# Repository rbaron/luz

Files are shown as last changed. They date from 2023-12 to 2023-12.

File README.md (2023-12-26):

# luz
An experiment in USB-C power delivery.

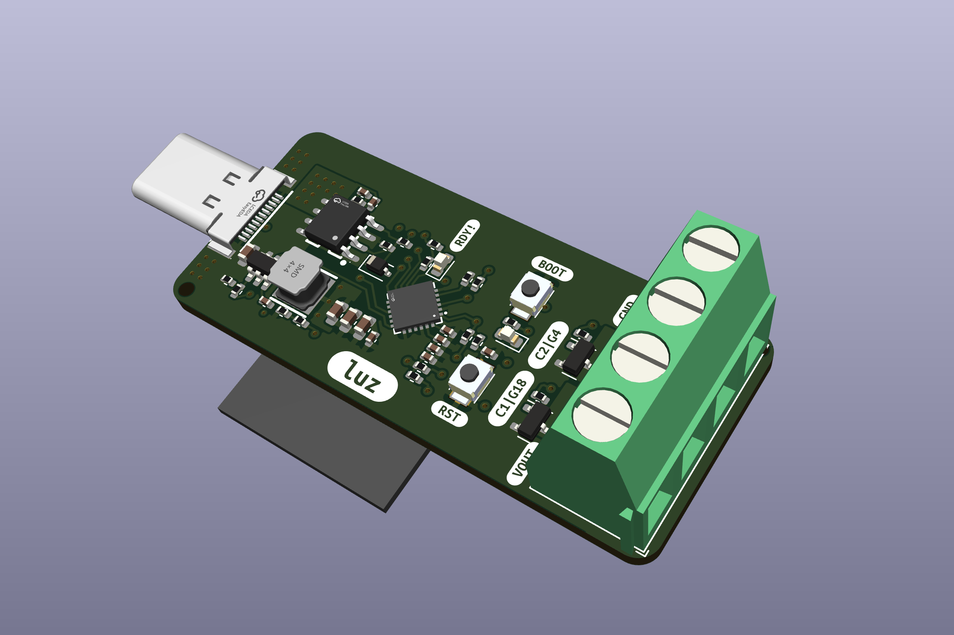
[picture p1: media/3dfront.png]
PCB render front


This repo contains printed circuit board fabrication files and firmware sample for a basic USB-C power delivery "trigger board" with an accompanying ESP32.

## Hardware
The CYPD3177 IC is used to negotiate power contracts with USB-C power supplies, and communicates with the onboard ESP32 via I2C for control and monitoring.

Once the required power delivery contract is successfully negotiated, the ESP32 may control two MOSFET channels to switch power to two different loads. The original use case is to deliver 12 V @ 3 A to LED strips, but any load up to 3A and 20V may be used in principle.

### Main Components
- [CYPD3177](https://www.infineon.com/cms/en/product/universal-serial-bus/usb-c-charging-port-controllers/ez-pd-barrel-connector-replacement-bcr/cypd3177-24lqxq/) USB-C PD controller
- ESP32-WROOM-32
  - For this prototype I used this older module since I still have a bunch of them around.

## Software
The CYPD3177 is configured during runtime via I2C. I implemented the `cypd3177` component in an [ESPHome](https://esphome.io/) fork (at [rbaron/esphome/cypd3177](https://github.com/rbaron/esphome/tree/cypd3177)).

In this repo there are sample `yaml` files under [./code/esphome](./code/esphome) that uses the `cypd3177` as an external component.

To configure a power delivery contract, set up the `cypd3177` component in ESPHome as for example:
```yaml
cypd3177:
  interrupt_pin: GPIO23
  voltage: 9000 mV
  current: 1000 mA
```

## USB-C Power Delivery Support & Maximum Power
The CYPD3177 supports USB-C PD 3.0, but unfortunately does not support Programmable Power Supply (PPS) contracts. The board is a prototype, mostly for learning, designed to handle a maximum of only 3 A.

USB-C PD 3.0 mandates support for a few standard fixed power profiles, namely providing 5 V, 9 V, 15 V and 20 V. Some USB-C PD sources may also support 12 V. Enabling logging for the `cypd3177` component in ESPHome will show the power profiles supported by the source. For example:

```
16:08:41.416 -> [I][cypd3177.pdo:059]: Fixed PDO: 5000 mV, 3000 mA
16:08:41.416 -> [I][cypd3177.pdo:059]: Fixed PDO: 9000 mV, 3000 mA
16:08:41.416 -> [I][cypd3177.pdo:059]: Fixed PDO: 12000 mV, 2000 mA
16:08:41.416 -> [I][cypd3177.pdo:059]: Fixed PDO: 15000 mV, 2000 mA
16:08:41.416 -> [I][cypd3177.pdo:059]: Fixed PDO: 20000 mV, 1500 mA
16:08:41.416 -> [I][cypd3177.pdo:066]: Augmented SPR_PPS PDO: 3300 - 11000 mV, 3000 mA
```

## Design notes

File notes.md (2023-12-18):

# ICs
- [STUSB4500](https://www.st.com/en/interfaces-and-transceivers/stusb4500.html)
  - $2 on JLCPCB
  - Open source project that uses it
    - [schematic](https://github.com/oxplot/fpx/blob/master/board/schematics.svg)
  - [Eval board](https://www.st.com/resource/en/data_brief/eval-scs001v1.pdf)
  - Main transistor on VBus_EN_SNK
    - How important is the power dissipation? Well very, ofc
    - Recommended on datasheet [STL6P3LLH6](https://www.st.com/resource/en/datasheet/stl6p3llh6.pdf)
      - -30V, -6A, 30mOhm, 3W
      - Max Vgs +-12
    - [AO3401A](https://datasheet.lcsc.com/lcsc/1810171817_Alpha---Omega-Semicon-AO3401A_C15127.pdf)
      - -30V, -4A, Rdson 100mOhm, 1W
      - Vth -1V
      - At
    - []()
    - [IRFR9024NTRPBF](https://www.mouser.ch/datasheet/2/196/Infineon_IRFR9024N_DataSheet_v01_01_EN-3363169.pdf)
      - -55V, -11A, Rdson 0.2O0hm, 38W
      - Vth max -4V
      - Max Vgs -20V, more confortable limit
      - But Rdson is high
        - At 5A, 0.2 Ohm = 5W, that's a lot of wasted power
    - [SSM3J332R](https://datasheet.lcsc.com/lcsc/1806140422_TOSHIBA-SSM3J332R-LF_C146367.pdf)
      - -30V, -6A, Rdson 0.050Ohm, 1W
      - Vth ~ -1V
      - Rdson @ -12V 0.05. At 5A = 0.25W, sounds good.
      - Max Vgs -12V, so we're close to the limit
    - [IRF9Z34NSTRLPBF](https://jlcpcb.com/partdetail/181165-IRF9Z34NSTRLPBF/C169780)
      - +- 20V Vgs, but 0.1 mOhm. At 5Amps, 2.5W, it's a lot
    - [DMP3028LFDE](https://jlcpcb.com/partdetail/DiodesIncorporated-DMP3028LFDE13/C150441)
      - [datasheet](https://www.diodes.com/assets/Datasheets/DMP3028LFDE.pdf)
      - Vgs +-20V, 5 Amps
      - 0.4 W only power dissipation
      - Rdson 0.04 Ohm. At 5 Amps, it's 1.25 W, above the 0.4 W limit
    - [AOD413A](https://jlcpcb.com/parts/componentSearch?searchTxt=AOD413A)
      - -40V, -12A, Rdson 0.045 Ohm, 1.5W
			- Vgs +-20V
    - [dmp3098lsd-13](https://datasheet.lcsc.com/lcsc/2009161504_Diodes-Incorporated-DMP3098LSD-13_C531177.pdf)
      - Dual P Channel
      - Used by Phil's design
      - Abs max Vgs +-20V, only 4.4 A?
    - [DMP3056LSS](https://datasheet.lcsc.com/lcsc/1806090929_Diodes-Incorporated-DMP3056LSS-13_C110502.pdf)
      - -30V, -6A, 0.045 Ohm, 1.5W
    - [SI4909DY-T1-GE3](https://www.digikey.ch/en/products/detail/vishay-siliconix/SI4909DY-T1-GE3/4439625)
      - 40V 8A 27mΩ@10V,8A 3.2W
      - [datasheet](https://datasheet.lcsc.com/lcsc/1806030436_Vishay-Intertech-SI4909DY-T1-GE3_C222523.pdf)
      -

# PD
	- Note that 12V is not part of the spec, but it's a common voltage. Anker apparently does not implement it?
  	- What if we request 15V @ 5A and add a buck converter to 12V?
	- Max 100 W (let's design for 100W but aim for max 50W for safety)
  	- At 12V, that's 8.3A
  	- But actually max current is 5A, only reaches 100W @ 20V
  	- So we can design with a 5A limit for the MOSFETs while observing the 100W limit
	- LED strips
  	- Depends on density of leds, ceiling is around 20 W/m, so we could power ~5 m tops at 100W. But at 12V, we're looking more at around 60-ish W. Realistic, lets aim for 3 m.
  	- At 12 V, that would be 20 * 3 / 12 = 2.5 A across however many channels we have

# ESP32-S3
- [Phil's design](https://www.youtube.com/watch?v=yxU_Kw2de08)
  - [Schematic](https://github.com/pms67/ESP32-USB-Dongle/blob/main/ESP32_USB_Dongle-Schematic.pdf)
- Regulator
  - [AP2114](https://www.diodes.com/assets/Datasheets/AP2114.pdf)
  - [HT7333](https://www.angeladvance.com/HT73xx.pdf)
    - Up to 12V
    - Max 250mA
  - [AMS1117](http://www.advanced-monolithic.com/pdf/ds1117.pdf)
    - Max 15V
    - Basic part at $0.13 on LCSC
    - Max 1A
  - [SPX3819](https://jlcpcb.com/partdetail/Maxlinear-SPX3819M5_L_3_3TR/C9055)
    - Phils uses this one
    - Max 16V (it would be nice to support 20V just in case)
    - Abolsute max +/-20V, which is ok
  - [SPX1117M3](https://jlcpcb.com/partdetail/Maxlinear-SPX1117M3_L_3_3TR/C6862)
		- Max 20V, 800 mA
		- Perfect
- [ESP32-S3-WROOM-1](https://www.espressif.com/sites/default/files/documentation/esp32-s3-wroom-1_wroom-1u_datasheet_en.pdf)
  - Contains module schematics
- Design reference
  - [Hardware design guidelines](https://www.espressif.com/sites/default/files/documentation/esp32-s3_hardware_design_guidelines_en.pdf)
    - RF
			- LNA_IN source 35 + 10j page 16
			- Using pi network for 50 Ohm antenna
			- [Pi Network calculator](https://www.eeweb.com/tools/pi-match/)
			- Antenna
  			- [ANT3216LL00R2400A](https://jlcpcb.com/partdetail/Yageo-ANT3216LL00R2400A/C293767) sounds popular
    			- Lots of use on GitHub
		- Flash
  		- Phil uses [W25Q16JVSSIQ](https://jlcpcb.com/partdetail/WinbondElec-W25Q16JVSSIQ/C82317)
  		- Discontinued in favor of [W25Q16JVSSIQ](https://jlcpcb.com/partdetail/WinbondElec-W25Q16JVSSIQ/C131025)
  		- See [ESP32-S3-WROOM-1](https://www.espressif.com/sites/default/files/documentation/esp32-s3-wroom-1_wroom-1u_datasheet_en.pdf) schematic for pins
  		- GPIO45
    		- [Default pull down (page 22)](https://cdn-shop.adafruit.com/product-files/5477/esp32-s3_datasheet_en.pdf) which makes VDD_SPI be 3.3 what we want

# USB-C
- [ESP dev board](https://www.youtube.com/watch?v=IML9c_MsyQU)
  - Male connector with tabs from JLCPCB
  - 3 A
- [C2982483](https://jlcpcb.com/partdetail/gswitch-GT_USB8012A/C2982483)
  - 24 pins
  - 5A
  - Tabs
  - Fixture required for soldering, not ideal
- [C2938596](https://jlcpcb.com/partdetail/XkbConnectivity-U261_241N4BS2SS/C2938596)
  - 5A
  - Tabs
  - [Datasheet]()
  - We'll only need the "easy to access" A* pins on the front row, convenient
  - Any board thickness, easier
- [C319150](https://jlcpcb.com/partdetail/XkbConnectivity-U261_241N4BS60/C319150)
  - PCB edge mount
  - No extra tabs
  - 5A
  -
  - [datasheet](https://datasheet.lcsc.com/lcsc/2002271811_XKB-Connectivity-U261-241N-4BS60_C319150.pdf)
    - PCB width? 0.9 mm?
      - Has to be 0.8
  - Projects using it:
    - https://github.com/tillitis/tillitis-key1
    - https://github.com/bschan9228/MInG/tree/f5a2087e46fd469d9a58bee00fa3ce4dc36beebd/Hardware/Prototype/ESP_SoC
      - Also has RF circuit
      - [PCB thickness 0.8 mm](https://github.com/bschan9228/MInG/blob/f5a2087e46fd469d9a58bee00fa3ce4dc36beebd/Hardware/Prototype/ESP_SoC/ESP_SoC/v1/PCB_OUTPUT/READ%20THIS%20FIRST.txt)
        - So it fits the USB-C connector?
        - But it will change the 4 layer impedance calculation

# Tactile Switch
- [](https://jlcpcb.com/partdetail/gswitch-GT_TC054A_H035L1/C778158)
  - Edge mounted

# Power Delivery
- 12

# LED Switching MOSFETs
- [AO3400A](https://datasheet.lcsc.com/lcsc/1811081213_Alpha---Omega-Semicon-AO3400A_C20917.pdf)
  - For low side switching the LEDs
  - But we can't really do low side given the common GND of the LED strips
  - Max Vgs -12V, but if we do low side switching, we're at 3.3V
- [AO3401A](https://datasheet.lcsc.com/lcsc/1810171817_Alpha---Omega-Semicon-AO3401A_C15127.pdf)
	- -30V, -4A, Rdson 100mOhm, 1W
	- Vth -1V
	- Vgs max -12, we'd be too close to the limit?
  	- Maybe use a voltage divider to bring it down to 10V?
  	- Or a transducer
	- At 4A, -12V Vgs, 0.05 Ohm = 0.8 W, so we're kinda good for power dissipation?
- A popular controller H801 uses a level shifter between the PWM signals and the P-channel MOSFET gates:
  - [https://tinkerman.cat/post/closer-look-h801-led-wifi-controller](teardown)
	- [HC245 datasheet](https://www.ti.com/lit/ds/symlink/sn74hc245.pdf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)
  	- [At JLCPCB](https://jlcpcb.com/partdetail/Toshiba-74VHC245FT_BE/C8096)
  	- 3.3, 5V compatible
  	-

# Barrel jack
- 5.5mm OD, 2.1mm ID
  - [Example](5.5mm 2.1mm)
  - Positive center

# Buck Converter ICs
- [TPS61175PWPR](https://jlcpcb.com/partdetail/TexasInstruments-TPS61175PWPR/C43276)
  - 3A
- [LM2596DSADJG](https://jlcpcb.com/partdetail/Onsemi-LM2596DSADJG/C92134)
  - 3A
  - SMT
- [AOZ1212](https://aosmd.com/res/data_sheets/AOZ1212AI.pdf)
  - Used by the popular H801 controller
  - 4.5V to 27V input
- [AOZ1284](https://aosmd.com/res/data_sheets/AOZ1284PI.pdf)
  -
- [digikey search2](https://www.digikey.ch/en/products/filter/voltage-regulators-dc-dc-switching-regulators/739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)
- [digikey search](https://www.digikey.ch/en/products/filter/voltage-regulators-dc-dc-switching-regulators/739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)
- [AP64501](https://www.diodes.com/assets/Datasheets/AP64501.pdf)
  - 5A, Vin max 40V
  - Efficiency 90%

# LDO
- [7812](https://datasheet.lcsc.com/lcsc/2304140030_STMicroelectronics-L7812CV_C105651.pdf)
  - 1.5 A
  - Heat?
- Options for up to 20V:
  - [Digikey query](https://www.digikey.ch/en/products/filter/voltage-regulators-linear-low-drop-out-ldo-regulators/699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)
  - [](https://jlcpcb.com/parts/componentSearch?searchTxt=LM1117MPX)
    - Max 24V
    - 500 mA
    - Perfect for us
  - [LM1117MPX-3.3/NOPB](https://jlcpcb.com/partdetail/TexasInstruments-LM1117MPX_3_3NOPB/C9662)
    - Max 20V
  - [NCP718BSN330T1G](https://www.digikey.ch/en/products/detail/onsemi/NCP718BSN330T1G/9169776)
    - Max 24V
    - But only 300mA
  - [SY8303](https://datasheet.lcsc.com/lcsc/1811151653_Silergy-Corp-SY8303AIC_C97054.pdf)
    - Buck converter input up to 40V
    - It's the one Phil uses

# ESD protection
- [ESDA25P35](https://www.mouser.ch/datasheet/2/389/esda25p35_1u1m-1848969.pdf)
  - Recommended by the STUSB4500 datasheet
  - Standoff voltage 22V
- [ESDA25W](https://jlcpcb.com/partdetail/TechPublic-ESDA25W/C3021136)
  - Operating voltage 24V
  - Dual

# TODO
- [X] Voltage divider & ADC to measure VBUS
- [X] Expose Vhigh on a connector (in addition to LED drivers), so we can use the board as a simple USB-C trigger board
- [X] Mounting holes
  - Got rid because of space
- [X] ESD protection
- [X] Barrel jack (backward voltage?)
- [X] Test pads
- [ ] Can we also make it control addressable LED strips?
- [X] Text in the back: max 12V, X watts/Amps per channel
- [X] I2C pullups
- [X] Expose I2C pins
- [X] More ground stitching vias close to the screw on connector

# Projects
- [PD Micro](https://www.crowdsupply.com/ryan-ma/pd-micro)
  - Uses PHY USB-C controller FUSB302, not all-in-one PD IC like STUSB4500
  - [Hackaday](https://hackaday.com/2021/01/16/usb-c-programmable-power-supply-for-any-project/)
  - [GitHub](https://github.com/ryan-ma/PD_Micro)
- [ZY12PDN](https://github.com/manuelbl/zy12pdn-oss)
  - Open source firmware for common PD trigger board ZY12PDN
    - FUSB302B IC
    - STM32F030F4 MCU
    - [Hardware analysis](https://github.com/manuelbl/zy12pdn-oss/wiki/Hardware-analysis)
  - Uses PPS fallback if fixed voltage not supported!
- [Brian Lough's PD trigger boards review](https://www.youtube.com/watch?v=iumAnPiQSj8)
  - [His post on IronOS](https://github.com/Ralim/IronOS/issues/24#issuecomment-651659470)
- [PicoPD](https://hackaday.io/project/192576-picopd-usb-c-pd-30-pps-trigger-with-rp2040)
  - PPS and PD capable
  - Uses the [AP33772](https://www.diodes.com/part/view/AP33772)
    - Capable of both PD and PPS!!
- [Phil's lab USB-C Power Delivery hardware design](https://www.youtube.com/watch?v=W13HNsoHj7A)
  - Uses [CYPD3177](https://www.infineon.com/dgdl/Infineon-EZ-PD_BCR_Datasheet_USB_Type-C_Port_Controller_for_Power_Sinks-DataSheet-v03_00-EN.pdf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)
    - Does not support PPS, but [CYPD3171](https://www.infineon.com/dgdl/Infineon-EZ-PD(TM)_CCG3PA_Datasheet_USB_Type-C_Port_Controller-DataSheet-v09_00-EN.pdf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) does
    - Has built-in overvoltage protection and short to vbus protection

# PD / PPS ICs
- [STUSB4500](https://www.st.com/en/interfaces-and-transceivers/stusb4500.html)
  - The one I used
  - [datasheet](https://www.st.com/resource/en/datasheet/stusb4500l.pdf)
  - No PPS, but [alternatives](https://community.st.com/t5/interface-and-connectivity-ics/how-do-i-configure-the-stusb4500-as-a-pps-sink/m-p/251067/highlight/true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)
- [STUSB1602](https://www.mouser.ch/datasheet/2/389/stusb1602-1852125.pdf)
  - [datasheet](file:///Users/rbaron/Downloads/stusb1602%20(1).pdf)
  - PPS support
  - Overvoltage protection and short to vbus protection
  - [P-NUCLEO-USB002](https://www.st.com/en/evaluation-tools/p-nucleo-usb002.html)
    - STM32 + STUSB1602 dev board
    - $60 on digikey
- [FUSB302](https://datasheet.lcsc.com/lcsc/1809111642_onsemi-FUSB302BMPX_C132291.pdf)
  - Popular, lower level
  - [OSS library](https://github.com/Ralim/usb-pd)
  - How does it work?
    - [BMC](https://en.wikipedia.org/wiki/Differential_Manchester_encoding) Power Delivery
      - Interface between the CC pins and the MCU through i2c
      - [BMC](https://en.wikipedia.org/wiki/Bi-phase_mark_code)
  - Code on [chrome-os](https://github.com/coreboot/chrome-ec/blob/master/driver/tcpm/fusb302.c)
- [CYPD3175](https://jlcpcb.com/partdetail/3338697-CYPD317524LQXQT/C2952419)
  - For source side?
  - [datasheet](https://www.infineon.com/dgdl/Infineon-EZ-PD(TM)_CCG3PA_Datasheet_USB_Type-C_Port_Controller-DataSheet-v09_00-EN.pdf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)
  - PD & PPS
  - Built-in Arm M0
  - Built-in overvoltage protection and short to vbus protection
- [CYPD3177](https://www.infineon.com/dgdl/Infineon-EZ-PD_BCR_Datasheet_USB_Type-C_Port_Controller_for_Power_Sinks-DataSheet-v03_00-EN.pdf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)
  - Easy to setup in auto mode with fixed voltage
  - Also supports i2c interface -- see [BCR HPI Guide](https://www.infineon.com/dgdl/Infineon-EZ-PD_BCR_Host_Processor_Interface_Specification-Software-v01_00-EN.pdf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)
- [CYPD3176](https://www.infineon.com/dgdl/Infineon-CYPD3176-24LQXQ-DataSheet-v01_00-EN.pdf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)
  - Unfortunately, documents related to HPI are only released under NDA. [link](https://community.infineon.com/t5/USB-EZ-PD-Type-C/CYPD3176-HPI-Host-Processor-Interface-Specification-for-PPS-control/m-p/324119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)
- [IP2721](https://datasheet.lcsc.com/lcsc/2006111335_INJOINIC-IP2721_C603176.pdf)
  - Brian Lough uses in his trigger board (see [Github issue comment](https://github.com/Ralim/IronOS/issues/24#issuecomment-651659470))
  - Standalone, single resistor to set fixed voltage
- [STM32 chips](https://www.st.com/content/st_com/en/ecosystems/stm32-usb-c.html)
  - Some STM32 chips have integrated USB-C PD support
    - [Presentation](https://www.st.com/content/dam/ecosystems/stm32-usb-c/microcontrollers-stm32usb-c-pd-solutions-ove-babacarnguirane.pdf)
    - [STM32G071](https://datasheet.lcsc.com/lcsc/2304140030_STMicroelectronics-STM32G071RBT6_C432213.pdf)
      - $2 on JLC
    - STM32G0x1 support PD 3.0 + PPS (via BMC + PHY?)
  - [Getting started with USB-C And STM32G0 ecosystem](https://www.youtube.com/watch?v=-PjgWTHzGqM) by ST
  - [Video from ST](https://www.youtube.com/watch?v=-vsJhNIaHxE)
  - [STM32G071B-DISCO](https://www.digikey.ch/en/products/detail/stmicroelectronics/STM32G071B-DISCO/9925245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)
    - USB-C PD board analysis
  - [X-NUCLEO-SNK1M1](https://www.st.com/en/ecosystems/x-nucleo-snk1m1.html)
    - Expansion board for nucleo boards that support UCPD (USB C Power Delivery)
    - 100 W solution supporting Programmable Power Supply (PPS) function
    - $25 on [digikey](https://www.digikey.ch/en/products/detail/stmicroelectronics/X-NUCLEO-SNK1M1/13971814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)
    - Uses the [TCPP01-M12](https://datasheet.lcsc.com/lcsc/2211071530_STMicroelectronics-TCPP01-M12_C1121848.pdf) protection IC
      - It actually does the load switching?
    - Compatible nucleo boards: NUCLEO-G071RB, NUCLEO-G474RE and NUCLEO-G0B1RE
      - NUCLEO-G071RB [$10 on digikey](https://www.digikey.ch/en/products/detail/stmicroelectronics/NUCLEO-G071RB/9739925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)
        - Target: [STM32G071RB](https://www.st.com/en/microcontrollers-microprocessors/stm32g071rb.html)
          - Has USB-C PD support
          - $2 on [JLC](https://jlcpcb.com/parts/componentSearch?searchTxt=STM32G071RB)
          - [Reference manual](https://www.st.com/resource/en/reference_manual/rm0444-stm32g0x1-advanced-armbased-32bit-mcus-stmicroelectronics.pdf)
            - Chapter 38: USB Type-C™ / USB Power Delivery interface (UCPD)
              - This is the info I WANTED!!!!
              - How to receive / transmit PD messages
              - 38.7.16 UCPD register map
          - [Reference design](https://www.st.com/resource/en/application_note/an5096-getting-started-with-stm32g0-series-hardware-development-stmicroelectronics.pdf)
          - [Explanation of USB pins](https://www.st.com/resource/en/product_training/STM32G0-Peripheral-USB-Type-C-Power-Delivery-UCPD.pdf)
  - Zephyr + STM32
    - [Zephyr USB-C Sink](https://docs.zephyrproject.org/latest/samples/subsys/usb_c/sink/README.html)
    - [nucleo_g071rb](https://github.com/zephyrproject-rtos/zephyr/tree/main/boards/arm/nucleo_g071rb)
      - [.dts] does not enable ucpd1?
      - but it's available at the SoC's [stm32g071.dtsi](https://github.com/zephyrproject-rtos/zephyr/blob/d34f725df81852b468dba2727a4d569022cb907d/dts/arm/st/g0/stm32g071.dtsi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)

# Docs
- [PD & PPS by Infineon](https://www.infineon.com/dgdl/Infineon-Universal_USB-C_Charger_Designs_Enabled_by_Programmable_Power_Supply-Whitepaper-v01_00-EN.pdf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)
  - Discusses PPS, PD
    - PD 2.0 introduces fixed voltages
      - Source sends Power Delivery Obj (PDO) messages with its capabilities
      - Sink selects one
    - PD 3.0 introduces PPS
      - Source sends message with its min/max voltage and current via Advanced Power Delivery Obj (APDO)
      - .. In addition to old 2.0 PDO
- [Low level PD @ hackaday](https://hackaday.com/2023/02/14/all-about-usb-c-talking-low-level-pd/)
  - Discusses PD 2.0?
  - Using the FUSB302 chip
  - Author references the [usb-pd lib](https://github.com/Ralim/usb-pd/tree/main/src/) used in IronOS (OSS soldering iron firmware?)
- [Protection for USB-C circuits](https://www.ti.com/lit/wp/slyy105/slyy105.pdf?ts=1700336340102&ref_url=https%253A%252F%252Fwww.google.com%252F)

# USB-C Protection ICs
- [TCPP01](https://www.st.com/resource/en/datasheet/tcpp01-m12.pdf)
  - Used in the nucleo boards
- [TPD8S300](https://www.ti.com/lit/ds/symlink/tpd8s300.pdf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)
  - $1 at JLC
- [NX20P0477](https://www.nxp.com/docs/en/data-sheet/NX20P0477.pdf)

# Ideas
## Fixed PD 2.0 LED driver
  - 5V (for some USB LED strips / lights) or 12V (for LED strips, but some adapters don't support 12V)
  - Max current A amps
  - Single channel
  - WIll use old ESP32 modules I have laying around
    - [Module ESP32­WROOM­32D](https://www.espressif.com/sites/default/files/documentation/esp32-wroom-32d_esp32-wroom-32u_datasheet_en.pdf)
    - [MCU datasheet](https://www.espressif.com/sites/default/files/documentation/esp32_datasheet_en.pdf)

# Chargers
## Small
- [Anker 313 Charger (Ace, 45W)](https://ankertechnologycompanyltd.my.salesforce.com/sfc/p/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)
  - $15 Black Friday
  - No 12V fixed
  - But does PPS 3.3V - 16V @ 3A
- [Anker Nano II 45W](https://ankertechnologycompanyltd.my.salesforce.com/sfc/p/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)
  - $27
  - No 12V fixed
  - But does PPS 3.3V - 16V @ 3A
- [Anker 511 Charger (Nano 3, 30W)](https://cdn.shopify.com/s/files/1/0595/4034/0926/files/A2147_User_Manual.pdf?v=1664433371)
  - $20
  - No 12V fixed
  - But does PPS 3.3V - 16V @ 2A
- [Anker PowerPort III Pod 65W](https://ru.anker.com/upload/iblock/ef9/y89gi14yuq3fje76wizdko6uvebsrp2o/A2712_PowerPort%20III%2065W%20Pod.pdf)
  - The one I have
  - No fixed 12V
  - Seems to do PPS 3.3V - 21V @ 3A
- [Anker Prime 100W (A2343)](https://ankertechnologycompanyltd.my.salesforce.com/sfc/p/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)
  - The one I have
  - Fixed 12V @ 3A
  - No PPS listing, but says in the bottom that it does support PPS?

# Dev Containers
- [zmk](https://github.com/zmkfirmware/zmk)
  - Uses their own [Docker image](https://github.com/zmkfirmware/zmk-docker/blob/3.2-branch/Dockerfile)

# STM32 dev board
- [nucleo_g071rb](https://www.st.com/en/evaluation-tools/nucleo-g071rb.html)
  - [User manual](https://www.st.com/resource/en/user_manual/dm00452640-stm32-nucleo-64-boards-with-stm32g07xrb-mcus-stmicroelectronics.pdf)
  - [Pinout](https://os.mbed.com/platforms/ST-Nucleo-G071RB/)
  - [Zephyr board](https://docs.zephyrproject.org/latest/boards/arm/nucleo_g071rb/doc/index.html)
    - `nucleo_g071rb`
  - [How to build a simple USB-PD sink application](https://www.mouser.com/pdfDocs/enDM006635111.pdf)
  - [Introduction to USB Type-C® Power Delivery for STM32](https://www.st.com/resource/en/application_note/dm00536349-usb-type-c-power-delivery-using-stm32xx-series-mcus-and-stm32xxx-series-mpus-stmicroelectronics.pdf)
    - Great resource with overview of USB-C PD / PPS
  - [Middleware USBPD Device G0](https://github.com/STMicroelectronics/stm32-mw-usbpd-device-g0)

## Building
```
ZEPHYR_BASE=~/dev/zephyr/zephyr west build -b nucleo_g071rb
```

## Flashing
With openocd:
```
openocd -f interface/stlink-v2.cfg  -f target/stm32g0x.cfg -c "program build/zephyr/zephyr.elf" -c "reset run" -c "shutdown"
```

## EZ - PD
- [Comparison](https://www.rutronik.com/electronic-components/infineon/moving-to-usb-c-with-infineons-ez-pdtm-family)
- BCR
  - [datasheet](https://www.infineon.com/dgdl/Infineon-EZ-PD_BCR_Datasheet_USB_Type-C_Port_Controller_for_Power_Sinks-DataSheet-v03_00-EN.pdf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)
  - CYPD3177
- BCR-Plus
  - [datasheet](https://www.infineon.com/dgdl/Infineon-CYPD3176-24LQXQ-DataSheet-v01_00-EN.pdf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)
  - Offers PPS
  - CYPD3176
-
- BCR-Lite

### HPI
- HPI for BCR-Plus and BCR-Lite
  - [specification](https://www.infineon.com/dgdl/Infineon-EZ-PD_TM_BCR-PLUS_BCR-LITE_HOST_PROCESSOR_INTERFACE_SPECIFICATION_CYPD3176_CYPD3178-UserManual-v01_00-EN.pdf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)
  - There's a PPS Request inside SINK_PDO_REQUEST
- HPI for BCR
  - [specification](https://www.infineon.com/dgdl/Infineon-EZ-PD_BCR_Host_Processor_Interface_Specification-Software-v01_00-EN.pdf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)

## USB-C PD
- Normal request
  - Page 259
- PPS request
  - Table 6.26 page 160
- PPS timers / keep alive
  - Page 290
  - Enough to keep requesting a PPS APDO as a keep alive every
    - tPPSRequest
      - Max 10s. We can do 5s
  - Page 491 has "steps for SPR PPS Keep Alive"
- Examples of messages
  - Changing PDOs, page 383

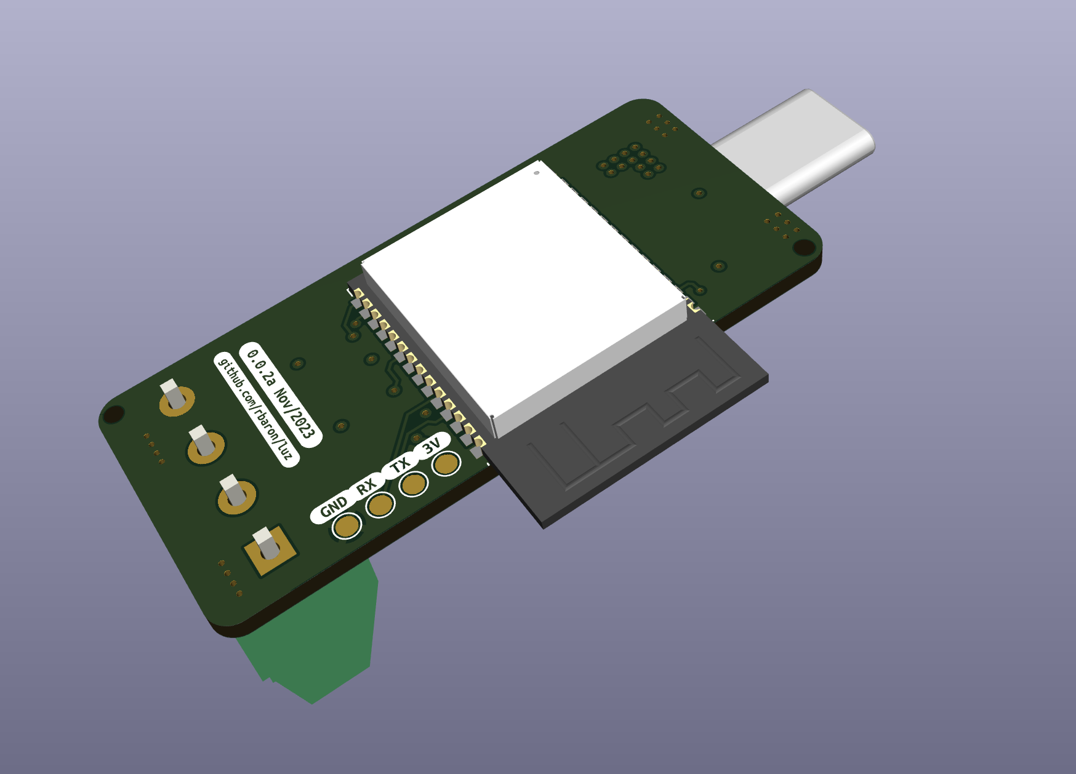
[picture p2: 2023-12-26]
media/3dback.png

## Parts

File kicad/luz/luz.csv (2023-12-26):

Comment | Designator | Footprint | LCSC
1u | C1,C4,C7,C10,C11 | Capacitor_SMD:C_0402_1005Metric | C52923
10u | C2,C3,C9,C12 | Capacitor_SMD:C_0603_1608Metric | C194427
100n | C5,C6,C8,C22 | Capacitor_SMD:C_0402_1005Metric | C77020
PO3 | D1,D4 | LED_SMD:LED_0603_1608Metric | C2286
15V | D3 | Diode_SMD:D_SOD-323 | C131825
47uH | L1 | footprint:IND-SMD_L4.0-W4.0_SLS3DXX | C54731
AO3400A | Q1,Q4 | Package_TO_SOT_SMD:SOT-23 | C20917
1k | R1,R3,R5,R6,R15 | Resistor_SMD:R_0402_1005Metric | C11702
100k | R10,R11 | Resistor_SMD:R_0402_1005Metric | C25741
470 | R13,R14 | Resistor_SMD:R_0402_1005Metric | C25117
22k | R16 | Resistor_SMD:R_0402_1005Metric | C25768
10k | R2,R12,R21,R22 | Resistor_SMD:R_0402_1005Metric | C25744
47k | R4 | Resistor_SMD:R_0402_1005Metric | C25792
4.7k | R7,R8,R9 | Resistor_SMD:R_0402_1005Metric | C25900
U261-241N-4BS2SS | U1 | footprint:USB-C-SMD_U261-241N-4BS2SS | C2938596
CYPD3177-24LQXQ_C2959321 | U2 | footprint:TQFN-24_L4.0-W4.0-P0.50-TL-EP2.8 | C2959321
SI4909DY-VB | U3 | footprint:SO-8_L4.9-W3.9-P1.27-LS5.9-BL | C710072
TPS54302 | U4 | Package_TO_SOT_SMD:SOT-23-6 | C311983

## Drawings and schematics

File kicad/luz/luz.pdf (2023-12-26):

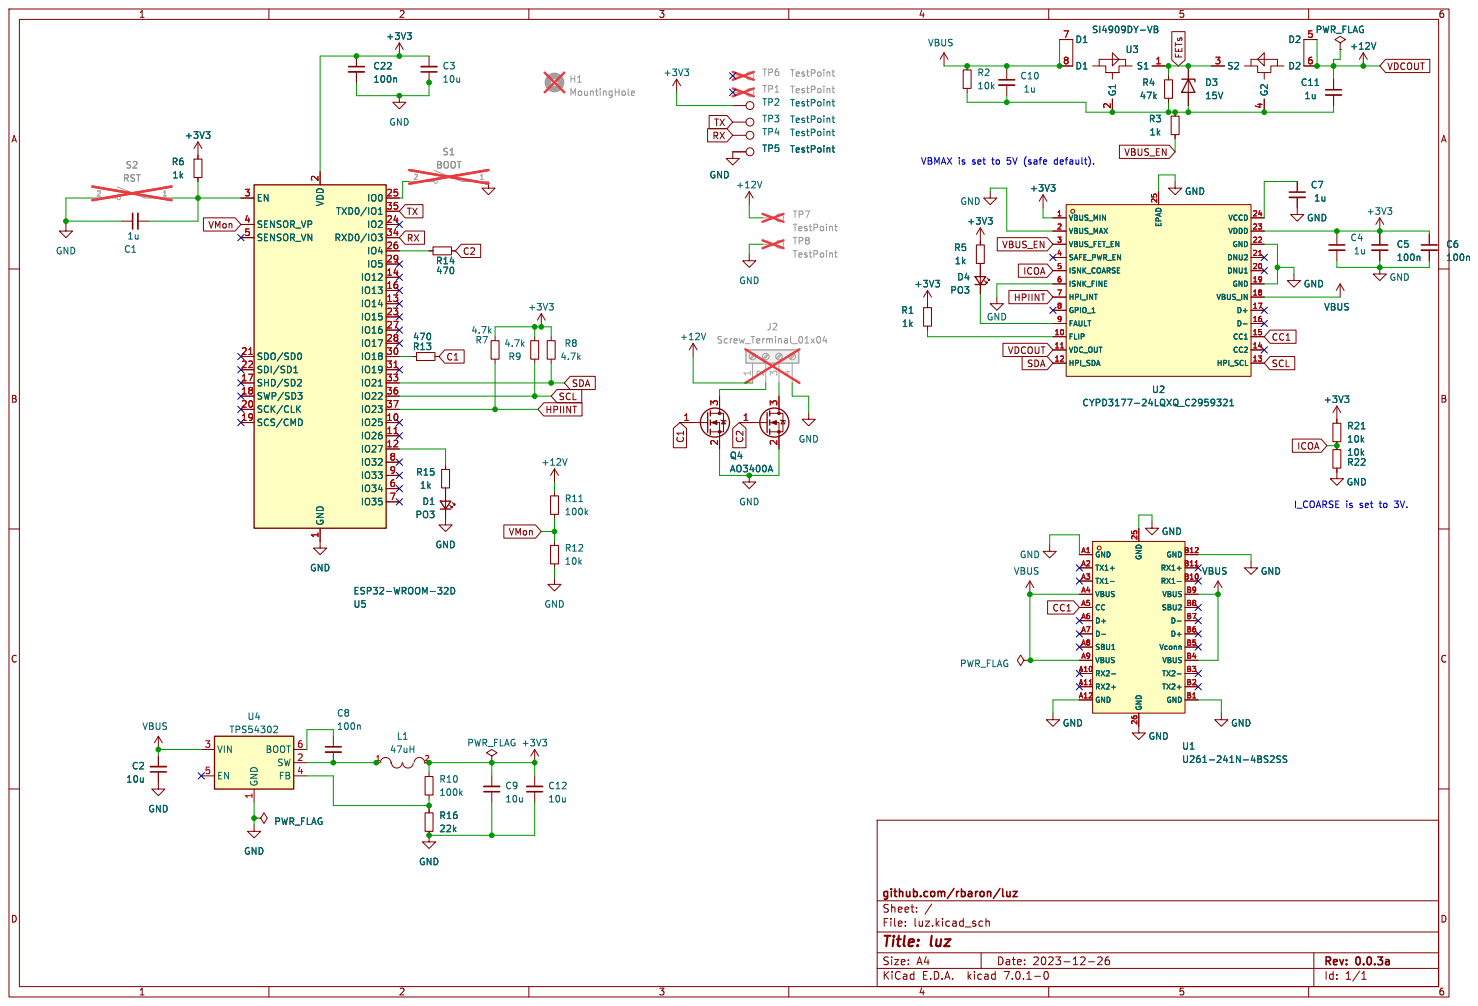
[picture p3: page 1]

TP6 TestPoint TP8 TestPoint GND
J2 Screw_Terminal_01x04 TP2 TestPoint TP1 TestPoint TP3 TestPoint TP5 TestPoint TP4 TestPoint

2 SCK/CLK 20 SDO/SD0 21 SDI/SD1 22

1 SW 2 VIN 3 FB 4 EN 5 BOOT 6 U4 TPS54302 GND

File: luz.kicad_sch Sheet: / github.com/rbaron/luz

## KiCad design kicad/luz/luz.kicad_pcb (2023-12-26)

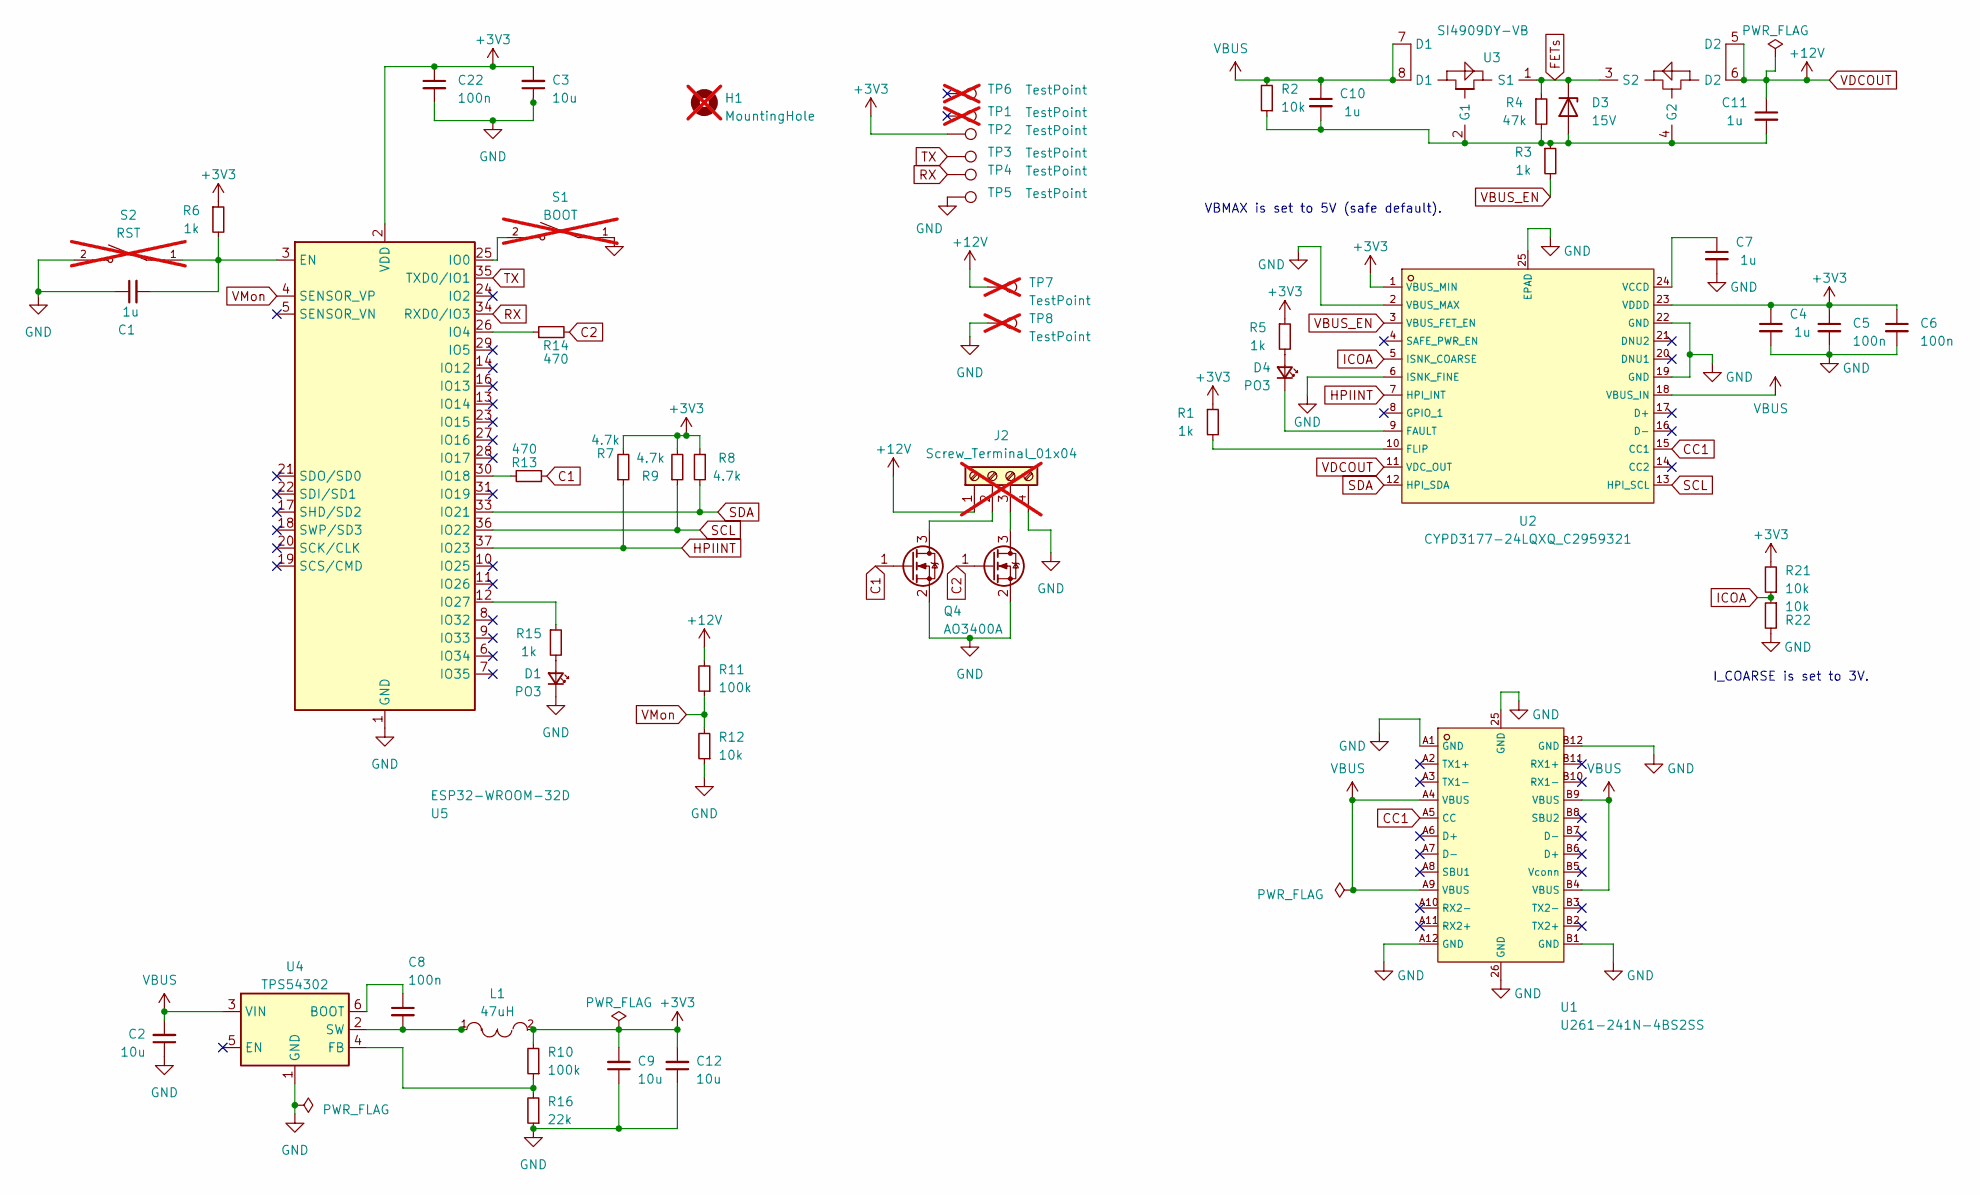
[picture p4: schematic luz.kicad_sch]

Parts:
C1, C4, C7, C10, C11: 1u; C_0402_1005Metric; LCSC C52923
C2, C3, C9, C12: 10u; C_0603_1608Metric; LCSC C194427
C5, C6, C8, C22: 100n; C_0402_1005Metric; LCSC C77020
D1, D4: PO3; LED_0603_1608Metric; LCSC C2286
D3: 15V; D_SOD-323; LCSC C131825
H1: MountingHole; MountingHole_2.2mm_M2_Pad_Via; not fitted
J2: Screw_Terminal_01x04; TerminalBlock_Phoenix_MKDS-1,5-4_1x04_P5.00mm_Horizontal; not fitted
L1: 47uH; IND-SMD_L4.0-W4.0_SLS3DXX; LCSC C54731
Q1, Q4: AO3400A; SOT-23; LCSC C20917
R1, R3, R5, R6, R15: 1k; R_0402_1005Metric; LCSC C11702
R2, R12, R21, R22: 10k; R_0402_1005Metric; LCSC C25744
R4: 47k; R_0402_1005Metric; LCSC C25792
R7, R8, R9: 4.7k; R_0402_1005Metric; LCSC C25900
R10, R11: 100k; R_0402_1005Metric; LCSC C25741
R13, R14: 470; R_0402_1005Metric; LCSC C25117
R16: 22k; R_0402_1005Metric; LCSC C25768
S1: BOOT; SW_B3U-1000P; LCSC C231329; not fitted
S2: RST; SW_B3U-1000P; LCSC C231329; not fitted
TP1, TP6: TestPoint; TestPoint_Pad_D1.5mm; not fitted
TP2, TP3, TP4, TP5: TestPoint; TestPoint_Pad_D1.5mm
TP7, TP8: TestPoint; TestPoint_Pad_4.0x4.0mm; not fitted
U1: U261-241N-4BS2SS; USB-C-SMD_U261-241N-4BS2SS; LCSC C2938596
U2: CYPD3177-24LQXQ_C2959321; TQFN-24_L4.0-W4.0-P0.50-TL-EP2.8; LCSC C2959321
U3: SI4909DY-VB; SO-8_L4.9-W3.9-P1.27-LS5.9-BL; LCSC C710072
U4: TPS54302; SOT-23-6; LCSC C311983
U5: ESP32-WROOM-32D

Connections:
+3V3: C3.2, C4.1, C5.1, C6.1, C9.2, C12.2, C22.1, L1.2, R1.1, R5.1, R6.1, R7.2, R8.1, R9.2, R10.2, R21.2, TP2.1, U2.1 (VBUS_MIN), U2.23 (VDDD), U5.2 (VDD)
C1: Q4.1 (G), R13.1
C2: Q1.1 (G), R14.2
CC1: U1.A5 (CC), U2.15 (CC1)
FETs: D3.1 (K), R4.1, U3.1 (S1), U3.3 (S2)
GND: C1.1, C2.1, C3.1, C4.2, C5.2, C6.2, C7.2, C9.1, C12.1, C22.2, D1.1 (K), J2.4, Q1.2 (S), Q4.2 (S), R12.1, R16.1, R22.2, S1.1, S2.2, TP5.1, TP8.1, U1.25 (GND), U1.26 (GND), U1.A1 (GND), U1.A12 (GND), U1.B1 (GND), U1.B12 (GND), U2.2 (VBUS_MAX), U2.6 (ISNK_FINE), U2.19 (GND), U2.22 (GND), U2.25 (EPAD), U4.1 (GND), U5.1 (GND), U5.15 (GND), U5.38 (GND), U5.39 (GND)
HPIINT: R7.1, U2.7 (HPI_INT), U5.37 (IO23)
ICOA: R21.1, R22.1, U2.5 (ISNK_COARSE)
unnamed: D1.2 (A), R15.2
unnamed: C10.2, C11.2, D3.2 (A), R2.1, R3.1, R4.2, U3.2 (G1), U3.4 (G2)
unnamed: D4.2 (A), R5.2
unnamed: D4.1 (K), U2.9 (FAULT)
unnamed: J2.2, Q4.3 (D)
unnamed: J2.3, Q1.3 (D)
unnamed: R1.2, U2.10 (FLIP)
unnamed: C7.1, U2.24 (VCCD)
unnamed: C8.1, U4.6 (BOOT)
unnamed: R10.1, R16.2, U4.4 (FB)
unnamed: C8.2, L1.1, U4.2 (SW)
unnamed: C1.2, R6.2, S2.1, U5.3 (EN)
unnamed: S1.2, U5.25 (IO0)
unnamed: R14.1, U5.26 (IO4)
unnamed: R13.2, U5.30 (IO18)
unnamed: R15.1, U5.12 (IO27)
RX: TP4.1, U5.34 (RXD0/IO3)
SCL: R9.1, U2.13 (HPI_SCL), U5.36 (IO22)
SDA: R8.2, U2.12 (HPI_SDA), U5.33 (IO21)
TX: TP3.1, U5.35 (TXD0/IO1)
VBUS: C2.2, C10.1, R2.2, U1.A4 (VBUS), U1.A9 (VBUS), U1.B4 (VBUS), U1.B9 (VBUS), U2.18 (VBUS_IN), U3.7 (D1), U3.8 (D1), U4.3 (VIN)
VBUS_EN: R3.2, U2.3 (VBUS_FET_EN)
VDCOUT: C11.1, J2.1, R11.2, TP7.1, U2.11 (VDC_OUT), U3.5 (D2), U3.6 (D2)
VMon: R11.1, R12.2, U5.4 (SENSOR_VP)

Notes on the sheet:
VBMAX is set to 5V (safe default).
I_COARSE is set to 3V.

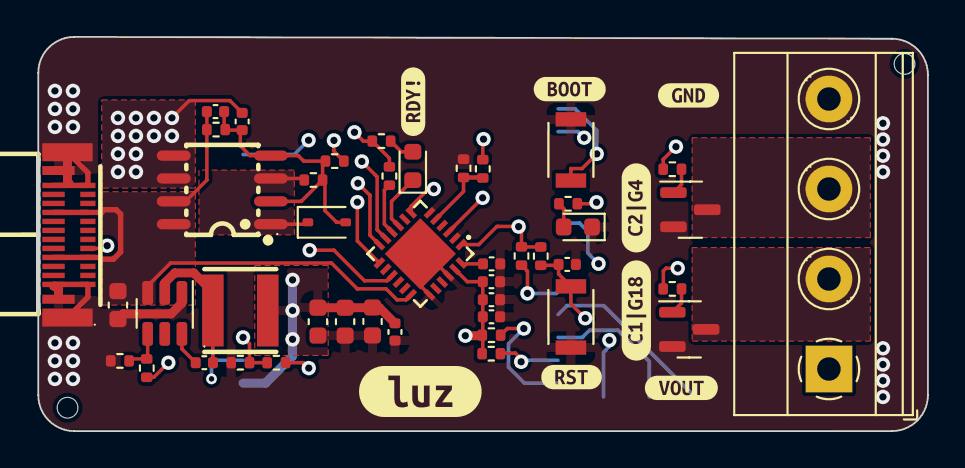
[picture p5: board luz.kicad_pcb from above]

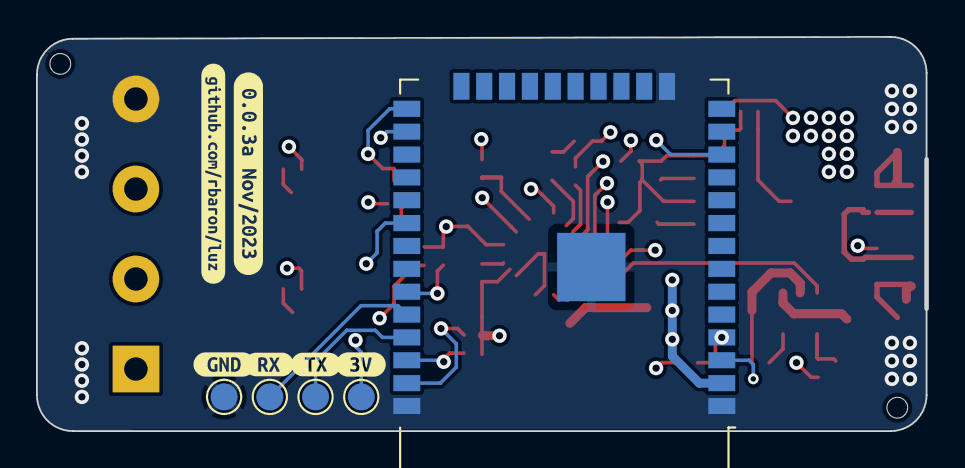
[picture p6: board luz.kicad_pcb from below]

Board: 4 copper layers, 49.4 x 21.9 mm, 63 parts (11 on the bottom side), 32 nets.

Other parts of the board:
kibuzzard-655BB0B1: G***; kibuzzard-655BB0B1
kibuzzard-655BB0BF: G***; kibuzzard-655BB0BF
kibuzzard-655BB09E: G***; kibuzzard-655BB09E
kibuzzard-655BB076: G***; kibuzzard-655BB076
kibuzzard-655BB97E: G***; kibuzzard-655BB97E
kibuzzard-655BB98B: G***; kibuzzard-655BB98B
kibuzzard-655BB458: G***; kibuzzard-655BB458
kibuzzard-655BB485: G***; kibuzzard-655BB485
kibuzzard-655BBA1E: G***; kibuzzard-655BBA1E
kibuzzard-655BBA6D: G***; kibuzzard-655BBA6D
kibuzzard-655BBA49: G***; kibuzzard-655BBA49
kibuzzard-658ADB24: G***; kibuzzard-658ADB24
kibuzzard-658AE3F9: G***; kibuzzard-658AE3F9
kibuzzard-658AE32D: G***; kibuzzard-658AE32D

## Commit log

2023-11-13 Initial routing
    [luz.kicad_pcb, luz.kicad_sch]
2023-11-13 Route DISCH pin through 1k resistor
    [luz.kicad_pcb, luz.kicad_sch]
2023-11-13 Pull down RST from STUSB45, as suggested by datasheet
    [luz.kicad_pcb, luz.kicad_sch]
2023-11-13 Connect shield
    [luz.kicad_pcb]
2023-11-13 Added missing LCSC numbers
    [luz.kicad_sch]
2023-11-14 Plotted files for production
    [luz-B_Cu.gbr, luz-B_Mask.gbr, luz-B_Paste.gbr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]
2023-11-20 Routed new version with ESP32-WROOM
    [luz.kicad_pcb, luz.kicad_sch]
2023-11-20 Better ground plane
    [luz.kicad_pcb]
2023-11-20 Fix schematic DRC
    [luz.kicad_pcb, luz.kicad_sch]
2023-11-20 Naming schematic values
    [luz.kicad_sch]
2023-11-20 Sent 0.0.2a for production
    [luz-B_Cu.gbr, luz-B_Mask.gbr, luz-B_Paste.gbr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]
2023-12-26 Adds 470 resistors to N FET channel drivers' gates & fix VBUSMAX
    [luz.kicad_pcb, luz.kicad_sch]
2023-12-26 Plotted fab outputs for 0.0.3a
    [luz-B_Cu.gbr, luz-B_Mask.gbr, luz-B_Paste.gbr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]
2023-12-26 Re-plotted fab files after making resistor designators invisible
    [luz-B_Cu.gbr, luz-B_Mask.gbr, luz-B_Paste.gbr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]
